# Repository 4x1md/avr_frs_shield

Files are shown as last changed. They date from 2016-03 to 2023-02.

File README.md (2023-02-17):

# AVR Fuse Rescue Shield for Arduino Uno
AVR Fuse Rescue Shield based on [Arduino-based AVR High Voltage Programmer](http://mightyohm.com/blog/2008/09/arduino-based-avr-high-voltage-programmer/) by Jeff Keyzer W6OHM aka [@mightyohm](https://twitter.com/mightyohm).

## Overview
While working on a new prototype for my [GPS module for Yaesu VX-8DR/DE transceivers](https://github.com/4x1md/vx8_gps), I made some newbie errors burning incorrect fuses into ATmega328P microcontrollers and bricked them. After some research I found [MightyOhm's High Voltage Programmer](http://mightyohm.com/blog/2008/09/arduino-based-avr-high-voltage-programmer/) which could bring them back to life. His programmer was designed as Arduino shield thus I could use the Arduino Uno board I already had. In my project I used MightOhm's schematics with minor changes and his Arduino code as is.

I made this device for recovering ATmega328P chips. It may be compatible with other ATmega's, but you have to check the compatibility before you try. This shield uses high voltage which may damage your microcontroller.

## Schematics
The schematics are almost the same as the original MightyOhm's. Two minor changes are:

1. Zener diode for getting 12V from unregulated power supply.
2. A led connected to microcontrollers Vcc line.

The shield requires external power supply of 12 to 16V. Unregulated power source will work fine.

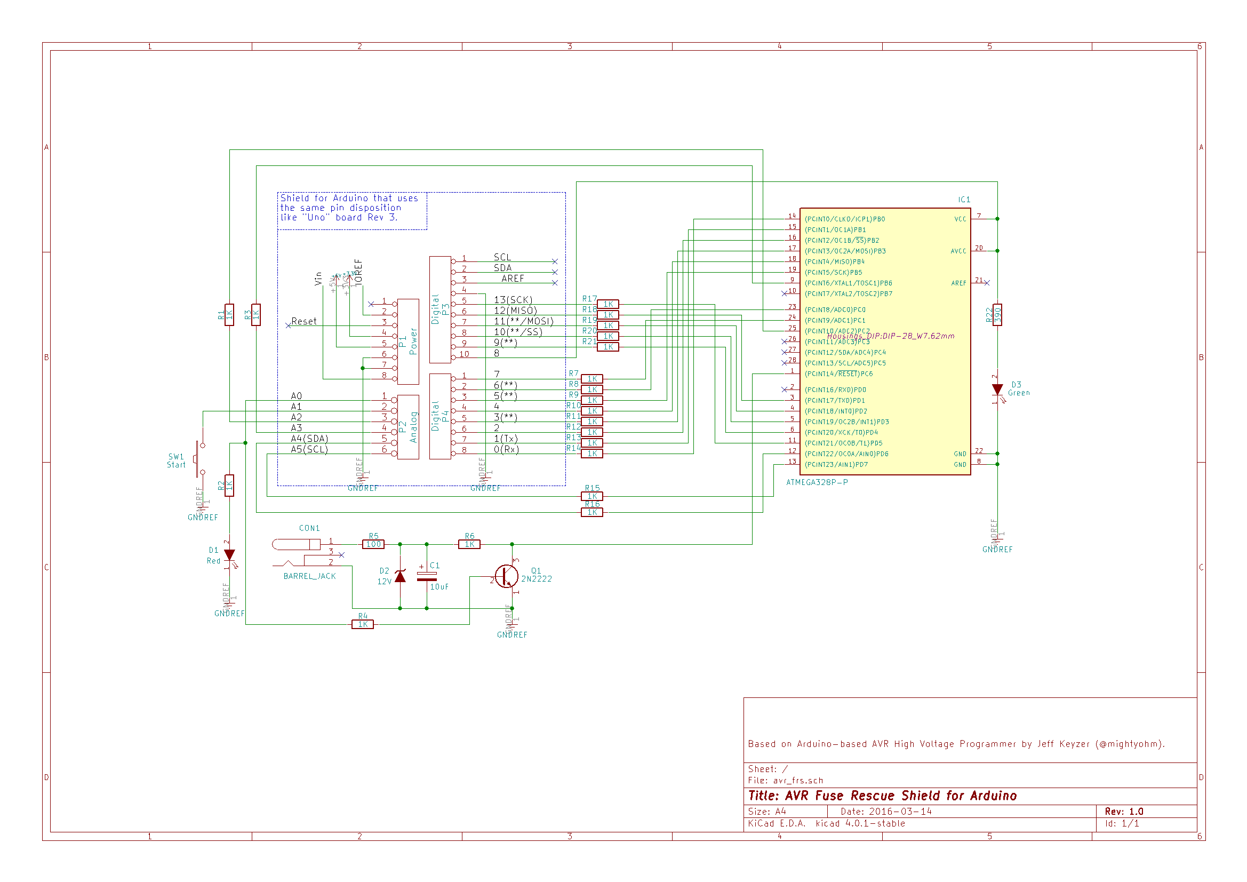
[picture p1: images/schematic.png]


## PCB Design
The PCB was designed using KiCAD software. As it was meant to be produced at home I designed it as single layer board. There are some front side tracks in the design which were replaced by jumper wires in the real PCB. Toner Transfer method was used to transfer the drawings to copper and front side.

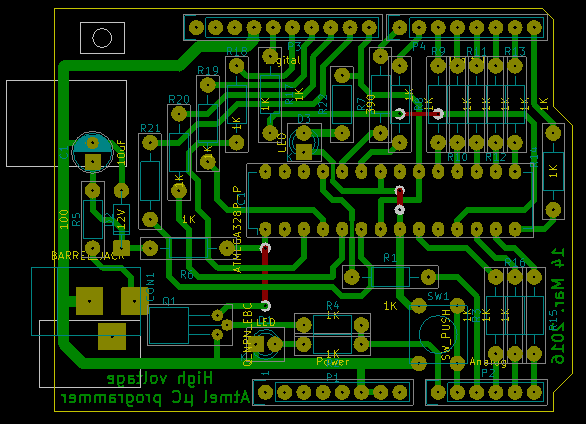
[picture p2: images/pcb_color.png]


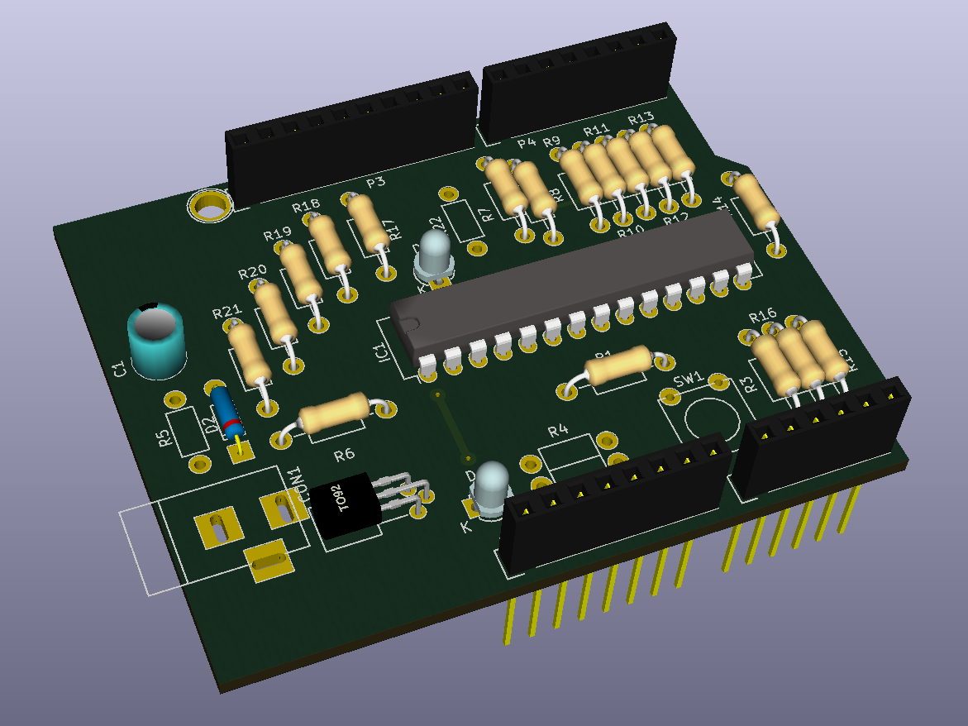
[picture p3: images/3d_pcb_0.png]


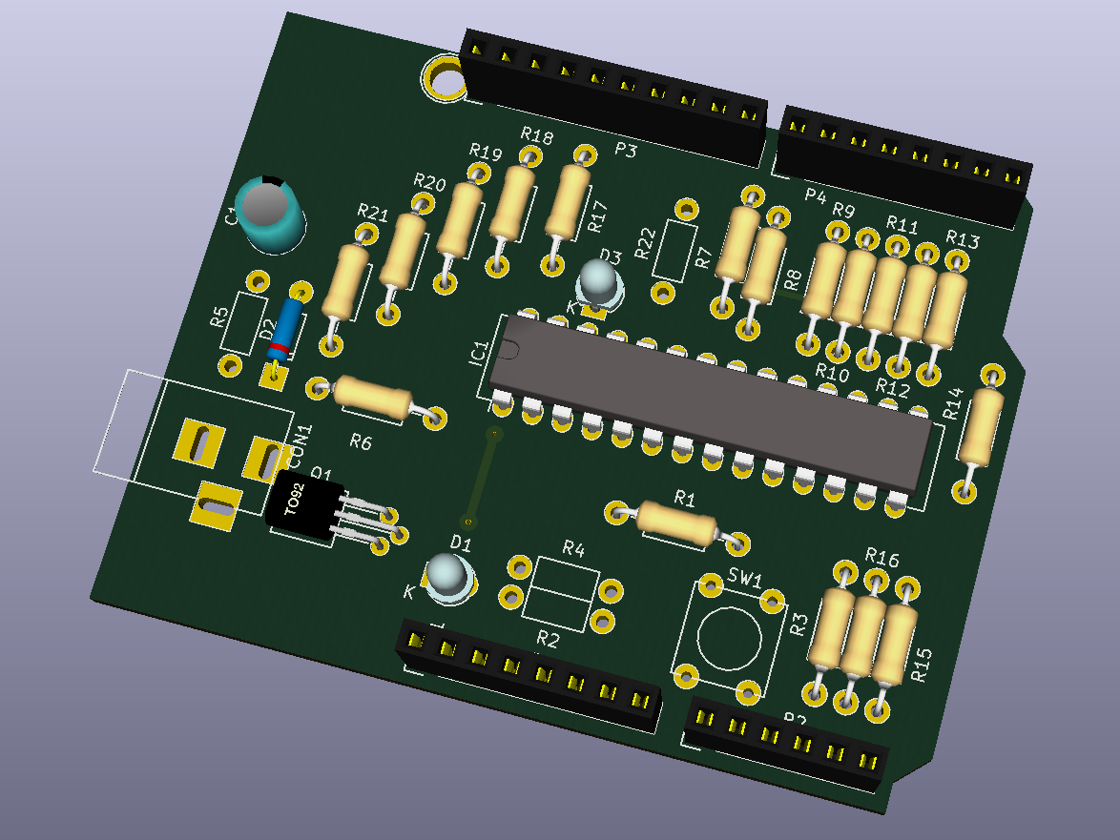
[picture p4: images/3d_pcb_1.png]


### Copper side
Print version: [avr_frs_pcb.pdf](https://github.com/4x1md/avr_frs_shield/blob/master/printable/avr_frs_pcb.pdf)

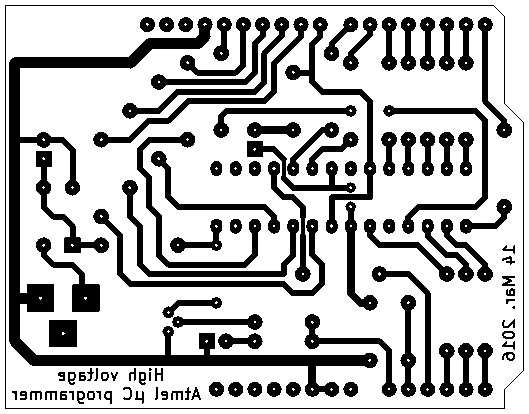
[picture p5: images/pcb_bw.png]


### Silk screen
Print version: [avr_frs-silk.pdf](https://github.com/4x1md/avr_frs_shield/blob/master/printable/avr_frs-silk.pdf)

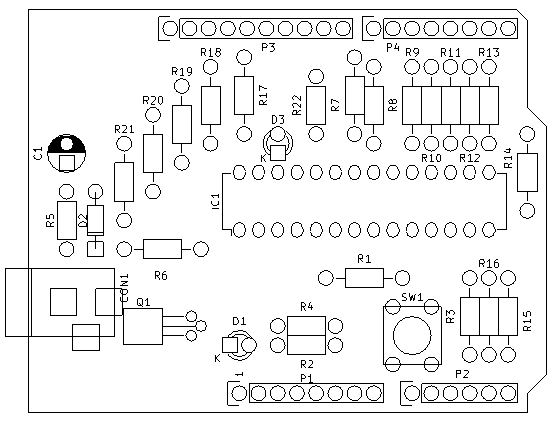
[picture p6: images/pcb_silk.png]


## Software
MightyOhm's original [Arduino code](https://github.com/4x1md/avr_frs_shield/tree/master/avr_frs_arduino) is used without any modifications.

## Alignment
Correctly assembled device requires no alignment.

## How To Use The Device

1. Upload the code to Arduino Uno or compatible board.
2. Connect the shield to the the Arduino.
3. Connect power sources to the Arduino board and to the shield. The red led will light and the green will not.
4. Place the device to recover in the dedicated socket.
5. Press the button on the shield. The green led will light and the red will turn off.
6. Wait until the leds return to their previous states.
7. Enjoy your unbricked microcontroller!

## Photos

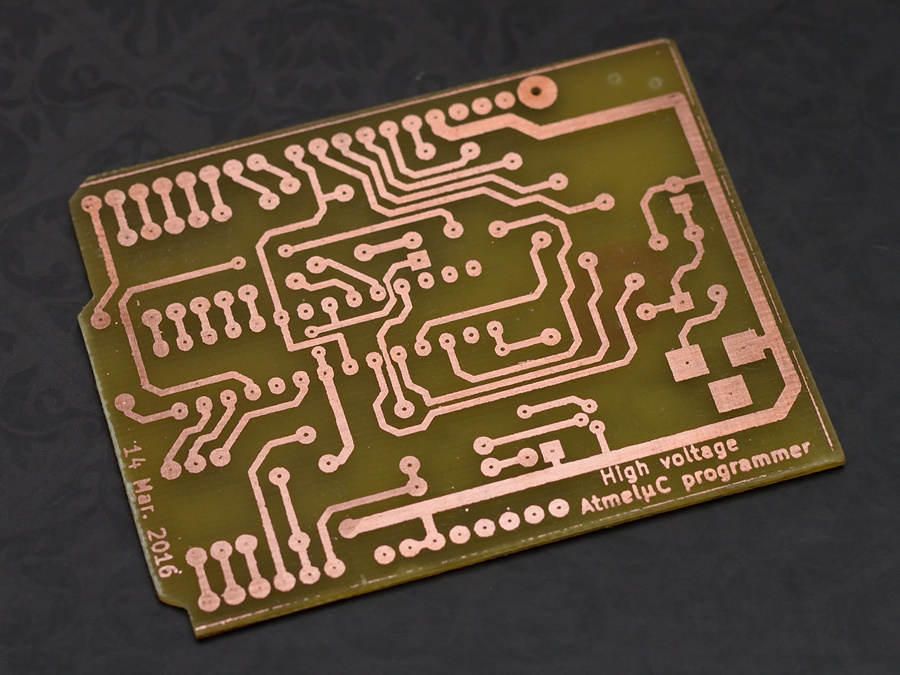
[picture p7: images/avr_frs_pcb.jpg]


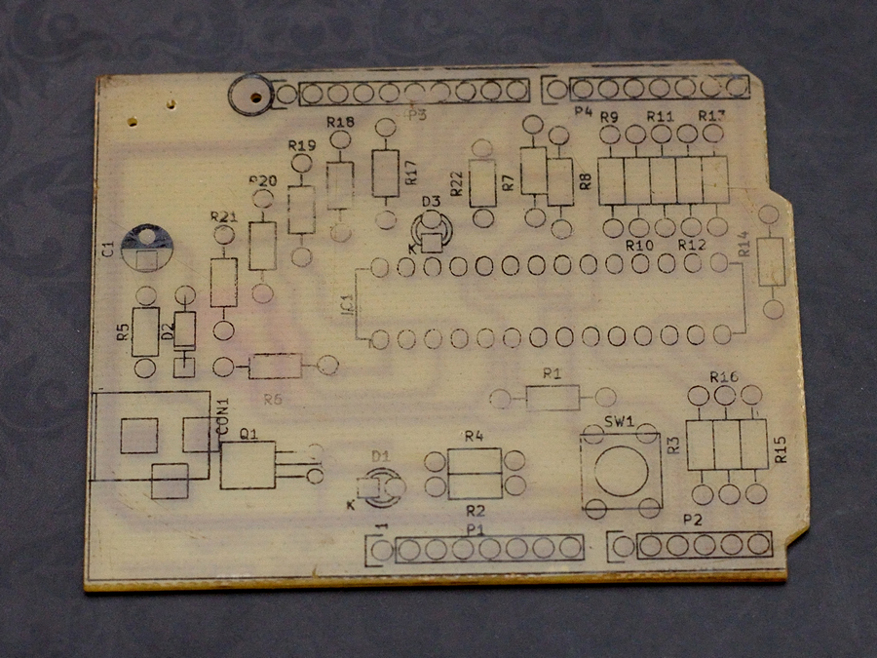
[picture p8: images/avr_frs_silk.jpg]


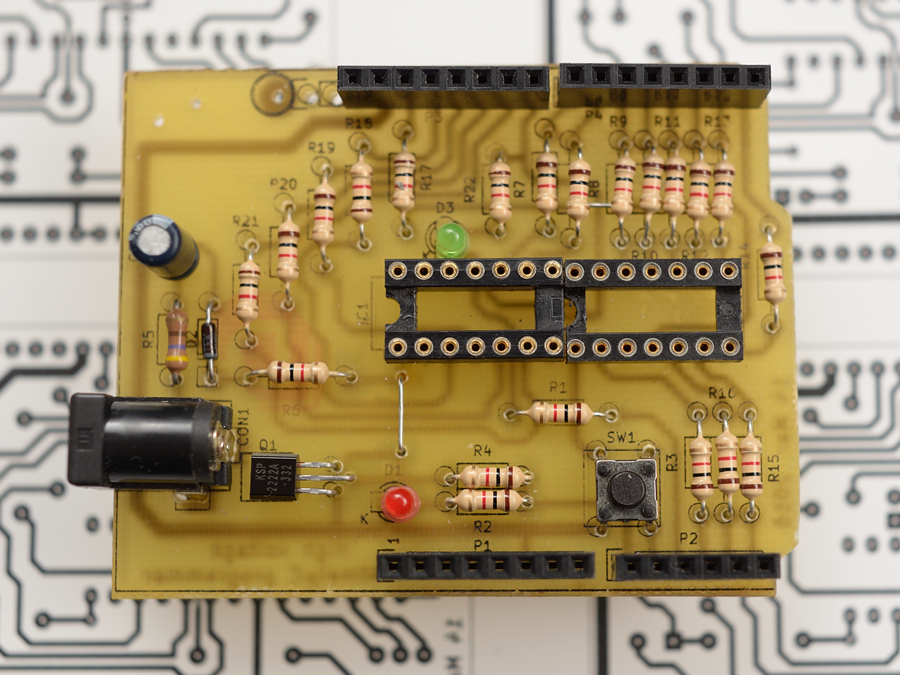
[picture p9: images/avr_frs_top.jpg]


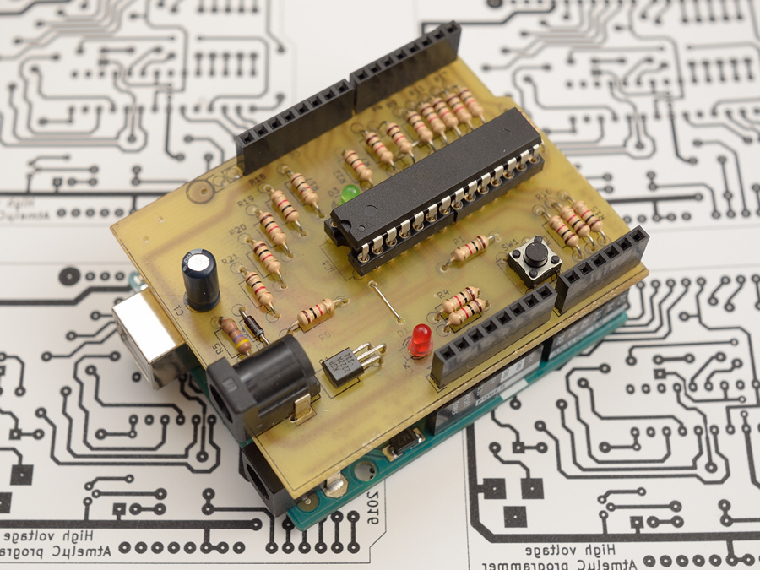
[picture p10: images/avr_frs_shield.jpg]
AVR Fuse Rescue Shield


## Sources
1. [Arduino-based AVR High Voltage Programmer](http://mightyohm.com/blog/2008/09/arduino-based-avr-high-voltage-programmer/)
2. [Jeff Keller aka @mightyohm's Twitter](https://twitter.com/mightyohm)
3. [Atmel ATmega328P datasheet](http://www.atmel.com/images/atmel-8271-8-bit-avr-microcontroller-atmega48a-48pa-88a-88pa-168a-168pa-328-328p_datasheet_complete.pdf)

## Questions? Suggestions?
You are more than welcome to contact me with any questions, suggestions or propositions regarding this project. You can:

1. Visit [my QRZ.COM page](https://www.qrz.com/db/4X1MD)
2. Visit [my Facebook profile](https://www.facebook.com/Dima.Meln)
3. Write me an email to iosaaris =at= gmail dot com

## How to Support or Say Thanks

If you like this project, or found here some useful information and want to say thanks, or encourage me to do more, you can buy me a coffee!



"Buy Me A Coffee" (https://www.buymeacoffee.com/4x1md)

You can aslo make a donation with PayPal:



---

**73 de 4X1MD**

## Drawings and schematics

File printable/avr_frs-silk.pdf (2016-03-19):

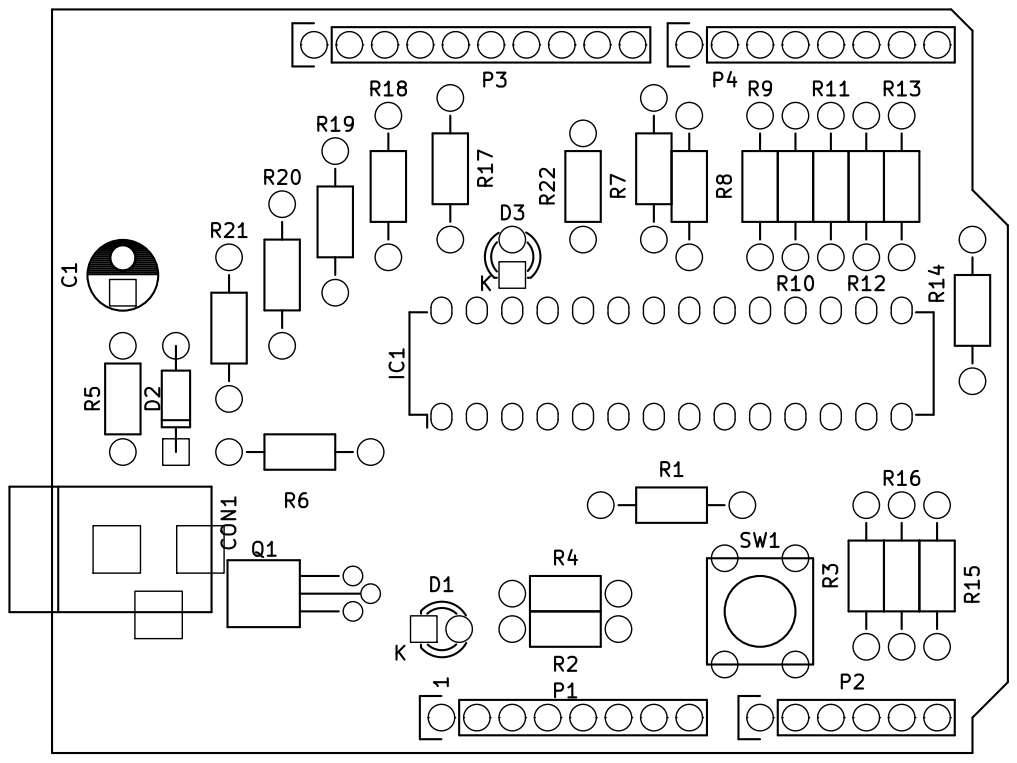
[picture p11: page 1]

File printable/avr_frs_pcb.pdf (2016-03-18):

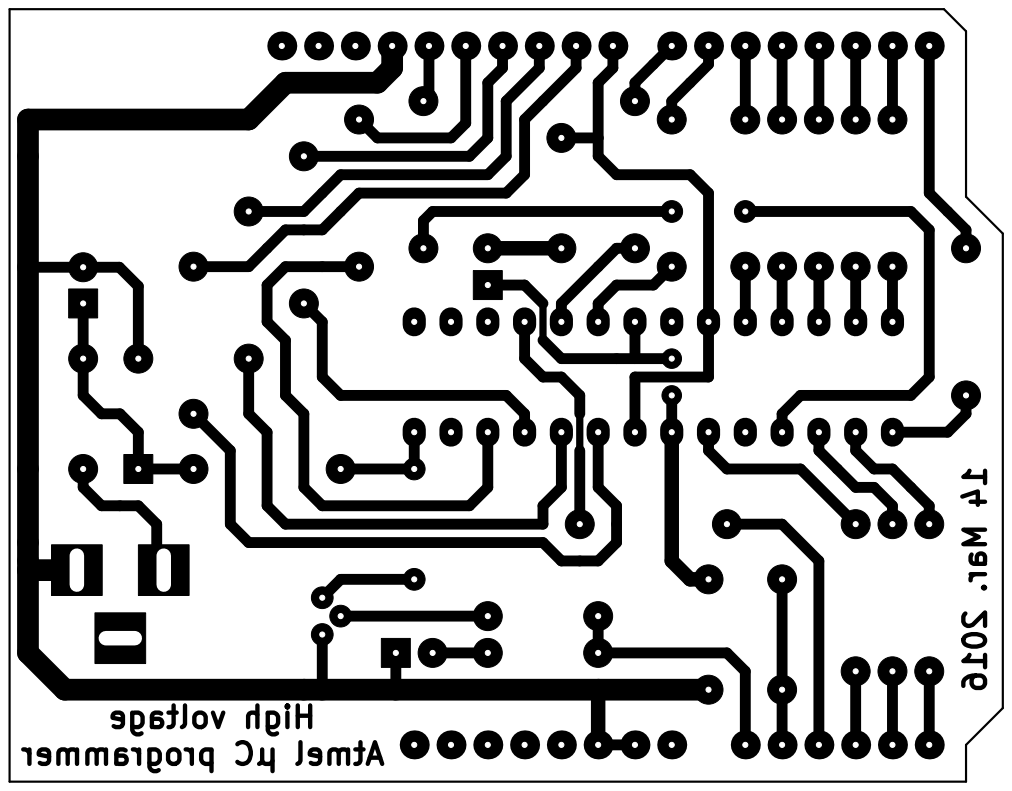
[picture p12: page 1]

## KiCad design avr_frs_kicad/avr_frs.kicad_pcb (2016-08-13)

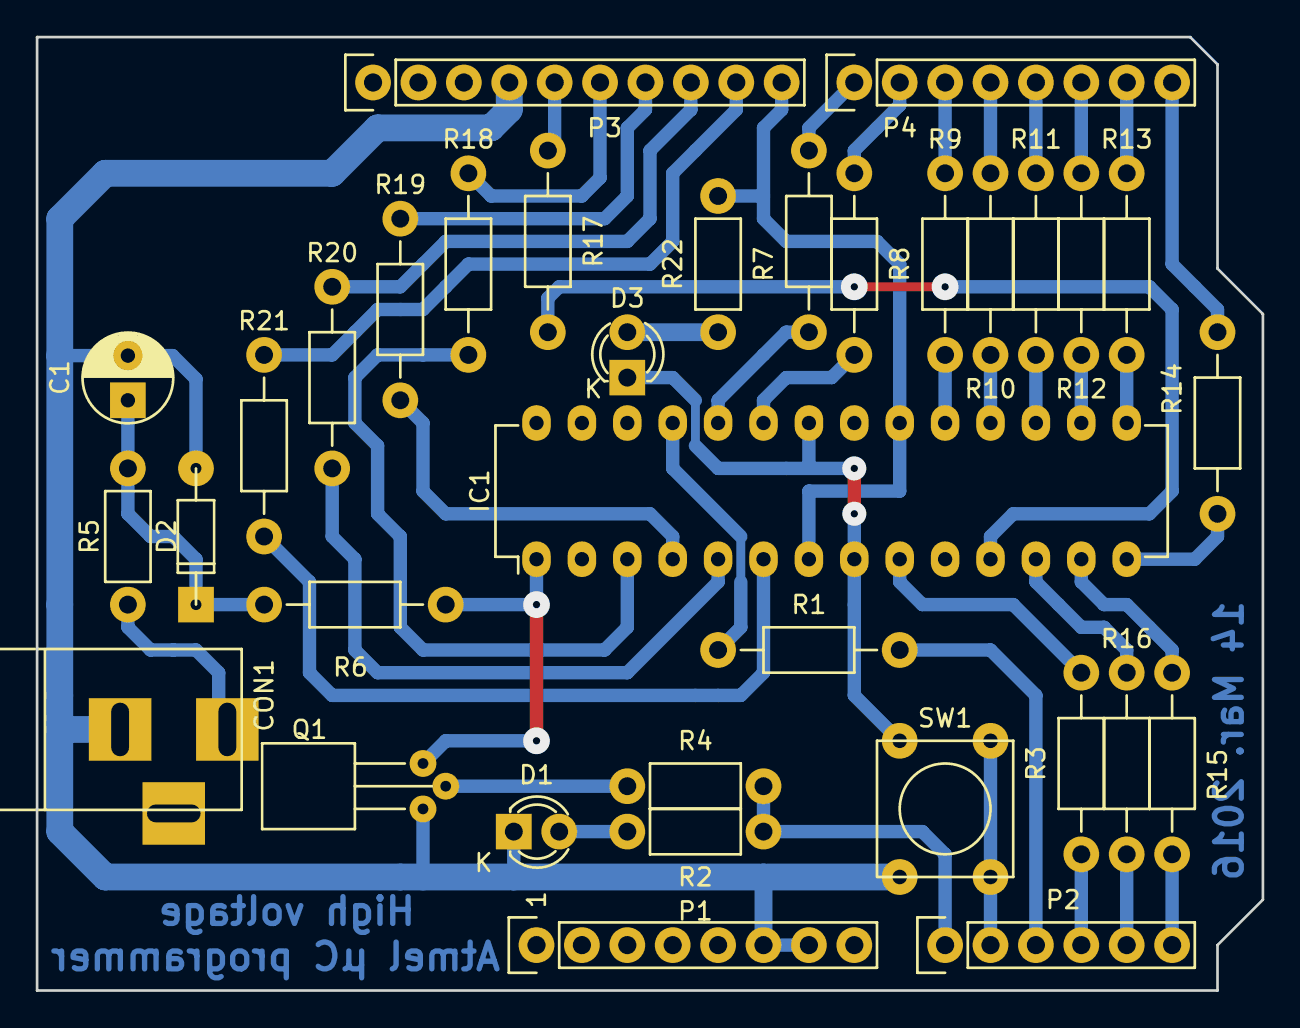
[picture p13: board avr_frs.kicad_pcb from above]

Board: 2 copper layers, 68.6 x 53.3 mm, 34 parts (0 on the bottom side), 44 nets.

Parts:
C1: 10uF; C_Radial_D5_L6_P2.5
CON1: BARREL_JACK
D1, D3: LED; LED-3MM
D2: 12V; DO-35
IC1: ATMEGA328P-P; DIP-28_W7.62mm
P1: Power; Socket_Strip_Arduino_1x08
P2: Analog; Socket_Strip_Arduino_1x06
P3: Digital; Socket_Strip_Arduino_1x10
P4: Digital; Socket_Strip_Arduino_1x08
Q1: Q_NPN_EBC; TO-92_Horizontal2_Molded_Narrow
R1, R3, R6, R7, R8, R9, R10, R11, R12, R13, R14, R15, R16, R17, R18, R19, R20, R21: 1K; Resistor_Horizontal_RM10mm
R2, R4: 1K; Resistor_Horizontal_RM7mm
R5: 100; Resistor_Horizontal_RM7mm
R22: 390; Resistor_Horizontal_RM7mm
SW1: SW_PUSH; SW_PUSH_SMALL

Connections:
/0(Rx): P4.8, R14.2
/1(Tx): P4.7, R13.2
/2: P4.6, R12.2
/3(**): P4.5, R11.2
/4: P4.4, R10.2
/5(**): P4.3, R9.2
/6(**): P4.2, R8.2
/7: P4.1, R7.2
/8: IC1.7, IC1.20, P3.10, R22.2
/9(**): P3.9, R21.2
/10(**/SS): P3.8, R20.2
/11(**/MOSI): P3.7, R19.2
/12(MISO): P3.6, R18.2
/13(SCK): P3.5, R17.2
/A0: P2.1, R2.1, R4.2
/A1: P2.2, SW1.2
/A2: P2.3, R1.2
/A3: P2.4, R3.2
/A4(SDA): P2.5, R16.2
/A5(SCL): P2.6, R15.2
GNDREF: C1.2, CON1.2, D1.1, D2.2, D3.1, IC1.8, IC1.22, P1.6, P1.7, P3.4, Q1.1, SW1.1
unnamed: C1.1, D2.1, R5.1, R6.2
unnamed: CON1.1, R5.2
unnamed: D1.2, R2.2
unnamed: D3.2, R22.1
unnamed: IC1.1, Q1.3, R6.1
unnamed: IC1.3, R18.1
unnamed: IC1.4, R19.1
unnamed: IC1.5, R20.1
unnamed: IC1.6, R21.1
unnamed: IC1.9, R3.1
unnamed: IC1.11, R17.1
unnamed: IC1.12, R16.1
unnamed: IC1.13, R15.1
unnamed: IC1.14, R14.1
unnamed: IC1.15, R13.1
unnamed: IC1.16, R12.1
unnamed: IC1.17, R11.1
unnamed: IC1.18, R10.1
unnamed: IC1.19, R9.1
unnamed: IC1.23, R8.1
unnamed: IC1.24, R7.1
unnamed: IC1.25, R1.1
unnamed: Q1.2, R4.1

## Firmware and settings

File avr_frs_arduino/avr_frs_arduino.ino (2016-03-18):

/*  
 HVFuse - Use High Voltage Programming Mode to Set Fuses on ATmega48/88/168
 09/23/08  Jeff Keyzer  http://mightyohm.com                
 The HV programming routines are based on those described in the
 ATmega48/88/168 datasheet 2545M-AVR-09/07, pg. 290-297
 This program should work for other members of the AVR family, but has only
 been verified to work with the ATmega168.  If it works for you, please
 let me know!  http://mightyohm.com/blog/contact/
 */

// Desired fuse configuration
#define  HFUSE  0xDF   // Default for ATmega48/88/168, for others see
#define  LFUSE  0x62   // http://www.engbedded.com/cgi-bin/fc.cgi

// Pin Assignments
#define  DATA    PORTD // PORTD = Arduino Digital pins 0-7
#define  DATAD   DDRD  // Data direction register for DATA port
#define  VCC     8
#define  RDY     12     // RDY/!BSY signal from target
#define  OE      11
#define  WR      10
#define  BS1     9
#define  XA0     13
#define  XA1     18    // Analog inputs 0-5 can be addressed as
#define  PAGEL   19    // digital outputs 14-19
#define  RST     14    // Output to level shifter for !RESET
#define  BS2     16
#define  XTAL1   17

#define  BUTTON  15    // Run button

void setup()  // run once, when the sketch starts
{
  // Set up control lines for HV parallel programming
  DATA = 0x00;  // Clear digital pins 0-7
  DATAD = 0xFF; // set digital pins 0-7 as outputs
  pinMode(VCC, OUTPUT);
  pinMode(RDY, INPUT);
  pinMode(OE, OUTPUT);
  pinMode(WR, OUTPUT);
  pinMode(BS1, OUTPUT);
  pinMode(XA0, OUTPUT);
  pinMode(XA1, OUTPUT);
  pinMode(PAGEL, OUTPUT);
  pinMode(RST, OUTPUT);  // signal to level shifter for +12V !RESET
  pinMode(BS2, OUTPUT);
  pinMode(XTAL1, OUTPUT);

  pinMode(BUTTON, INPUT);
  digitalWrite(BUTTON, HIGH);  // turn on pullup resistor

  // Initialize output pins as needed
  digitalWrite(RST, HIGH);  // Level shifter is inverting, this shuts off 12V
}

void loop()  // run over and over again
{
  while(digitalRead(BUTTON) == HIGH) {  // wait until button is pressed
  }
  // Initialize pins to enter programming mode
  digitalWrite(PAGEL, LOW);
  digitalWrite(XA1, LOW);
  digitalWrite(XA0, LOW);
  digitalWrite(BS1, LOW);
  digitalWrite(BS2, LOW);
  // Enter programming mode
  digitalWrite(VCC, HIGH);  // Apply VCC to start programming process
  digitalWrite(WR, HIGH);  // Now we can assert !OE and !WR
  digitalWrite(OE, HIGH);
  delay(1);
  digitalWrite(RST, LOW);   // Apply 12V to !RESET thru level shifter
  delay(1);
  // Now we're in programming mode until RST is set HIGH again
  
  // First we program HFUSE
  sendcmd(B01000000);  // Send command to enable fuse programming mode
  writefuse(HFUSE, true);

  // Now we program LFUSE
  sendcmd(B01000000);
  writefuse(LFUSE, false);

  delay(1000);  // wait a while to allow button to be released

  // Exit programming mode
  digitalWrite(RST, HIGH);

  // Turn off all outputs
  DATA = 0x00;
  digitalWrite(OE, LOW);
  digitalWrite(WR, LOW);
  digitalWrite(PAGEL, LOW);
  digitalWrite(XA1, LOW);
  digitalWrite(XA0, LOW);
  digitalWrite(BS1, LOW);
  digitalWrite(BS2, LOW);
  digitalWrite(VCC, LOW);
}

void sendcmd(byte command)  // Send command to target AVR
{
  // Set controls for command mode
  digitalWrite(XA1, HIGH);
  digitalWrite(XA0, LOW);
  digitalWrite(BS1, LOW);
  //DATA = B01000000;  // Command to load fuse bits
  DATA = command;
  digitalWrite(XTAL1, HIGH);  // pulse XTAL to send command to target
  delay(1);
  digitalWrite(XTAL1, LOW);
  //delay(1);
}

void writefuse(byte fuse, boolean highbyte)  // write high or low fuse to AVR
{
  // if highbyte = true, then we program HFUSE, otherwise LFUSE
  
  // Enable data loading
  digitalWrite(XA1, LOW);
  digitalWrite(XA0, HIGH);
  delay(1);
  // Write fuse
  DATA = fuse;  // set desired fuse value
  digitalWrite(XTAL1, HIGH);
  delay(1);
  digitalWrite(XTAL1, LOW);
  if(highbyte == true)
    digitalWrite(BS1, HIGH);  // program HFUSE
  else
    digitalWrite(BS1, LOW);
  digitalWrite(WR, LOW);
  delay(1);
  digitalWrite(WR, HIGH);
  delay(100);
}

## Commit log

2016-03-18 Arduino code.
2016-03-18 KiCAD circuit & PCB.
    [avr_frs.kicad_pcb, avr_frs.sch]
2016-03-18 Schematic & 3D models.
2016-03-18 PCB in printable PDF.
2016-03-19 PCB and silk screen in PDF.
2016-08-13 Minor rerouting.
    [avr_frs.kicad_pcb]
